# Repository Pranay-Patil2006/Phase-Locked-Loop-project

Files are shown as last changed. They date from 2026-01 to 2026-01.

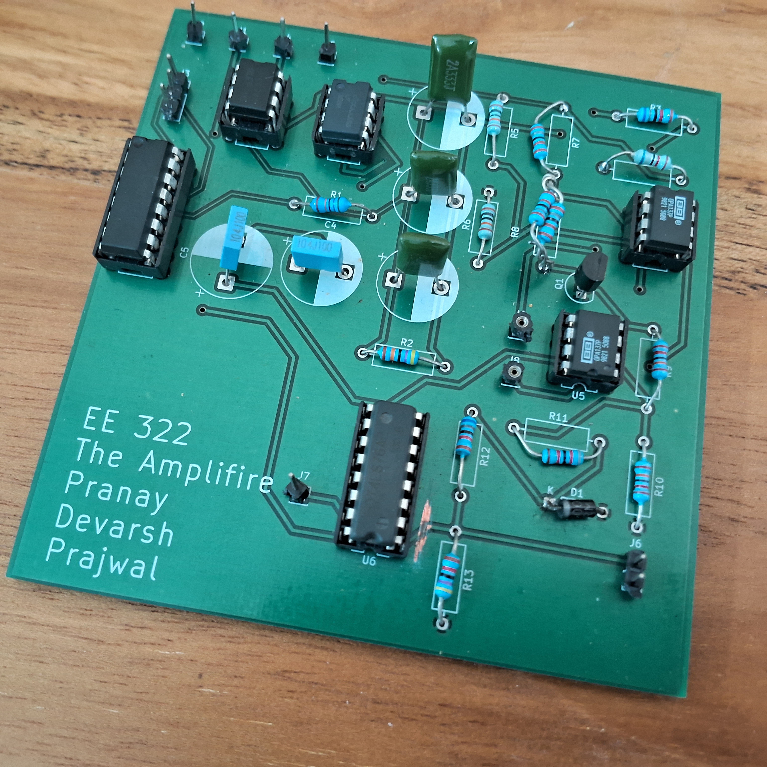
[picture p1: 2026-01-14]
images/PCB_soldered.jpg

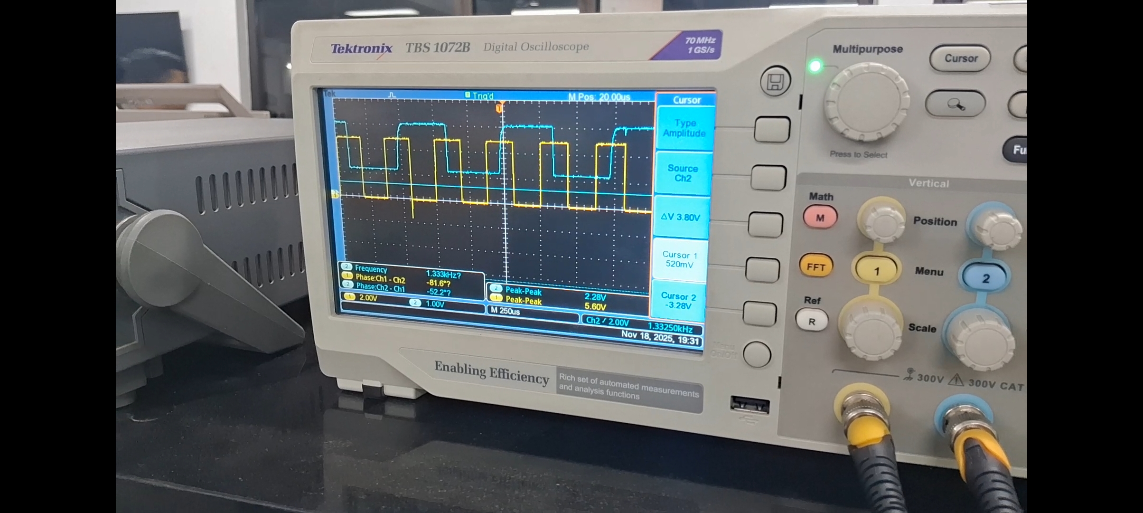
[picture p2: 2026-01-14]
images/Locking.jpg

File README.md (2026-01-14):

# Phase-Locked-Loop Project
**Design and implementation on PCB of a phase-locked loop**

---

## Summary
Designed, simulated, and validated a discrete analog Phase-Locked Loop (PLL) implemented on PCB using a CD4046 phase detector, discrete op-amps, and passive/active loop-filter components. The design was optimized to minimize phase jitter and maximize capture and lock range, with close agreement between simulation and hardware measurements.

---

## Key Contributions
- **Loop design & analysis:** Derived loop-filter values from the closed-loop transfer function; verified lock time and stability margins using time-domain analysis.
- **Simulation strategy:** Performed LTSpice transient simulations and parameter sweeps to evaluate capture range, locking behavior, and sensitivity to component variations.
- **Jitter reduction tactics:** Reduced jitter through optimized loop bandwidth selection, low-noise op-amp choice, VCO linearization, proper supply decoupling, and careful PCB routing of phase detector and VCO control nodes.
- **Validation:** Conducted testbench measurements of lock acquisition and short-term phase stability to confirm simulation trends and guide final component tuning.

---

## Block Diagram
Simple block diagram of the circuit

*Credits: https://electronicscoach.com/phase-locked-loops.html*

---

## Results
- **Measured capture/lock range:** 150Hz - 1300Hz

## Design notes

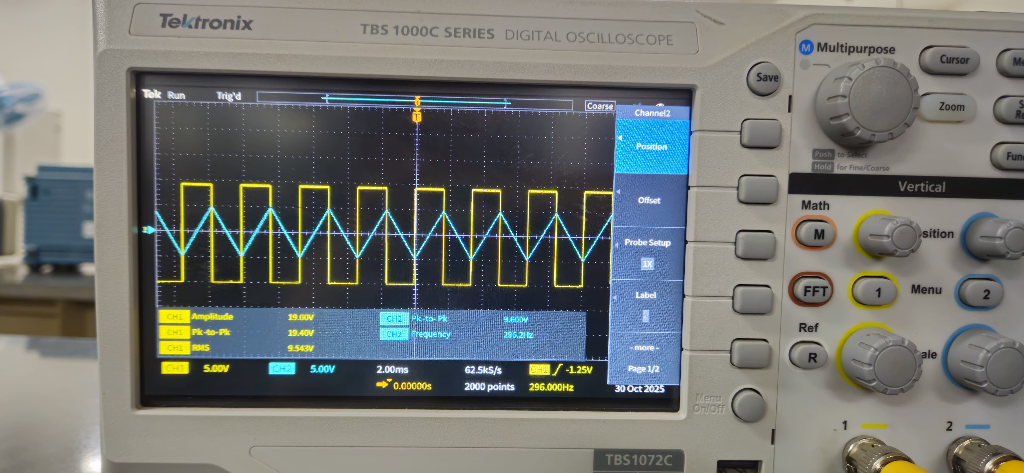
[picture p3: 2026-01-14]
images/VCO_output.jpg

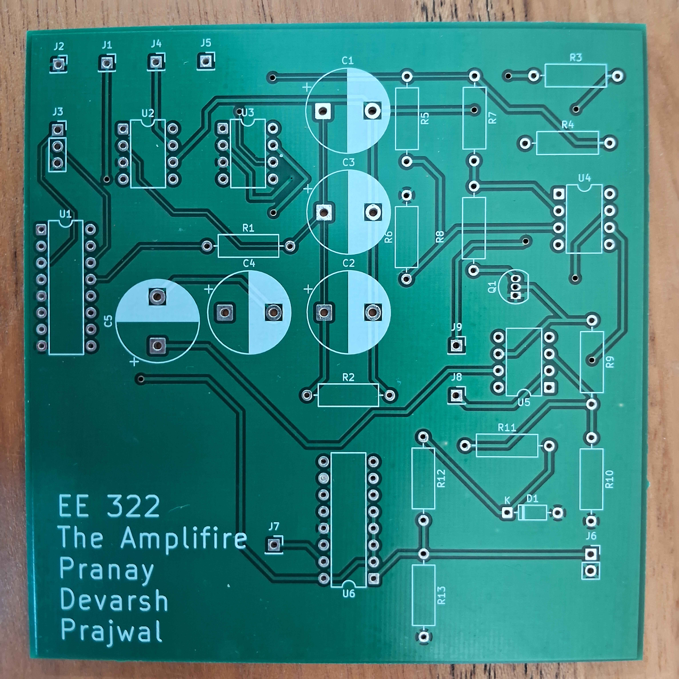
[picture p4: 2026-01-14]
images/PCB.jpg

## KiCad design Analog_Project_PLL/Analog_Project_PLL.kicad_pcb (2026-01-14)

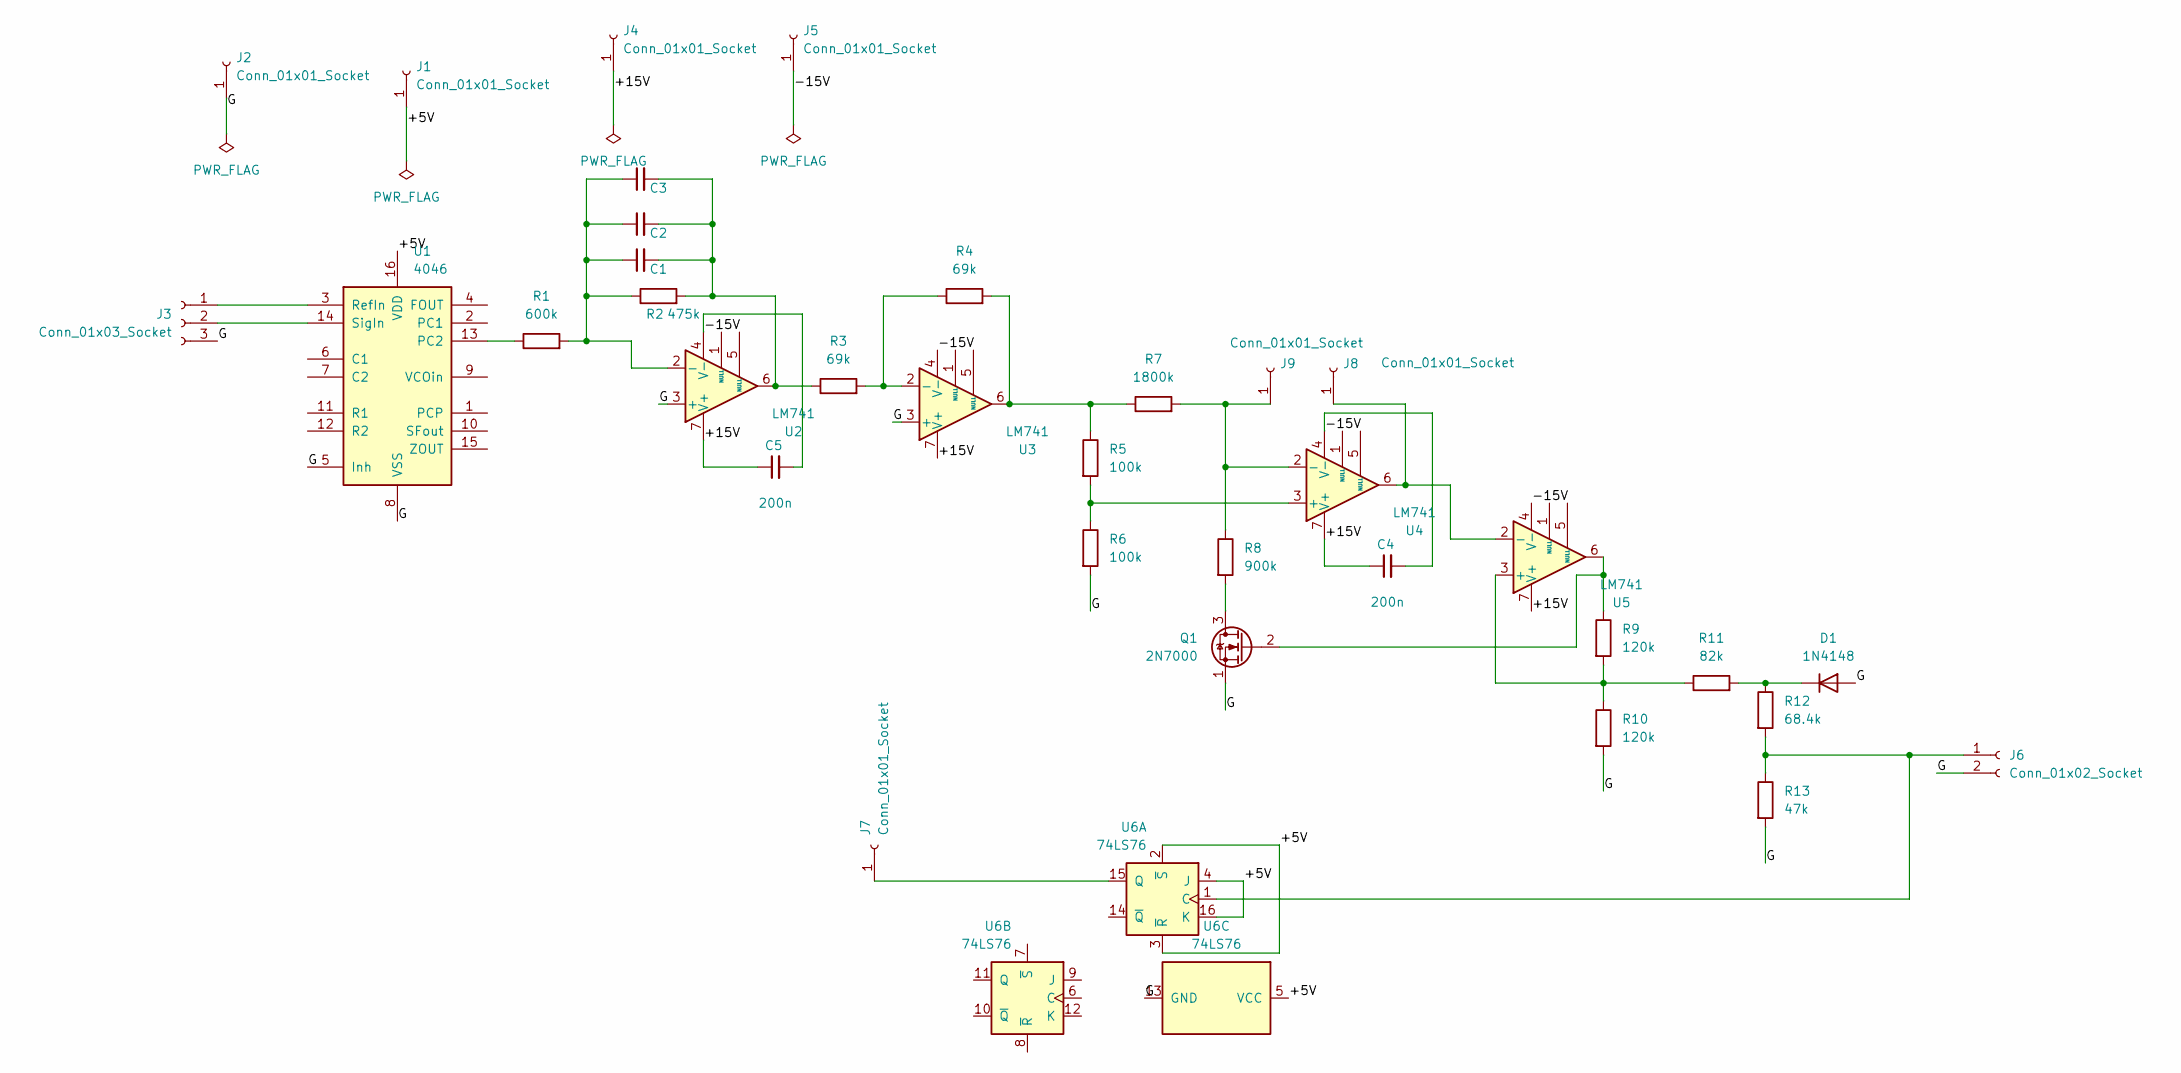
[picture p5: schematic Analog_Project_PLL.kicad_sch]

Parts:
C1, C2, C3: 33n; CP_Radial_D12.5mm_P7.50mm
C4, C5: 200n; CP_Radial_D12.5mm_P7.50mm
D1: 1N4148; D_DO-35_SOD27_P7.62mm_Horizontal
J1, J2, J4, J5, J7, J8, J9: Conn_01x01_Socket; PinSocket_1x01_P2.54mm_Vertical
J3: Conn_01x03_Socket; PinSocket_1x03_P2.54mm_Vertical
J6: Conn_01x02_Socket; PinSocket_1x02_P2.54mm_Vertical
Q1: 2N7000; TO-92_Inline
R1: 600k; R_Axial_DIN0309_L9.0mm_D3.2mm_P12.70mm_Horizontal
R2: 475k; R_Axial_DIN0309_L9.0mm_D3.2mm_P12.70mm_Horizontal
R3, R4: 69k; R_Axial_DIN0309_L9.0mm_D3.2mm_P12.70mm_Horizontal
R5, R6: 100k; R_Axial_DIN0309_L9.0mm_D3.2mm_P12.70mm_Horizontal
R7: 1800k; R_Axial_DIN0309_L9.0mm_D3.2mm_P12.70mm_Horizontal
R8: 900k; R_Axial_DIN0309_L9.0mm_D3.2mm_P12.70mm_Horizontal
R9, R10: 120k; R_Axial_DIN0309_L9.0mm_D3.2mm_P12.70mm_Horizontal
R11: 82k; R_Axial_DIN0309_L9.0mm_D3.2mm_P12.70mm_Horizontal
R12: 68.4k; R_Axial_DIN0309_L9.0mm_D3.2mm_P12.70mm_Horizontal
R13: 47k; R_Axial_DIN0309_L9.0mm_D3.2mm_P12.70mm_Horizontal
U1: 4046; DIP-16_W7.62mm
U2, U3, U4, U5: LM741; DIP-8_W7.62mm
U6: 74LS76; DIP-16_W7.62mm

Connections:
/+5V: J1.1, U1.16 (VDD), U6.2 (~S), U6.3 (~R), U6.4 (J), U6.5 (VCC), U6.16 (K)
/+15V: C4.1, C5.1, J4.1, U2.7 (V+), U3.7 (V+), U4.7 (V+), U5.7 (V+)
/-15V: C4.2, C5.2, J5.1, U2.4 (V-), U3.4 (V-), U4.4 (V-), U5.4 (V-)
/G: D1.2 (A), J2.1, J3.3, J6.2, Q1.1 (S), R6.2, R10.2, R13.2, U1.5 (Inh), U1.8 (VSS), U2.3 (+), U3.3 (+), U6.13 (GND)
unnamed: C1.2, C2.2, C3.2, R2.2, R3.1, U2.6
unnamed: D1.1 (K), R11.2, R12.1
unnamed: J3.1, U1.3 (RefIn)
unnamed: J3.2, U1.14 (SigIn)
unnamed: J6.1, R12.2, R13.1, U6.1 (C)
unnamed: J7.1, U6.15 (Q)
unnamed: J8.1, U4.6, U5.2 (-)
unnamed: J9.1, R7.2, R8.1, U4.2 (-)
unnamed: Q1.3 (D), R8.2
unnamed: Q1.2 (G), R9.1, U5.6
unnamed: R4.2, R5.1, R7.1, U3.6
unnamed: R1.1, U1.13 (PC2)
unnamed: C1.1, C2.1, C3.1, R1.2, R2.1, U2.2 (-)
unnamed: R3.2, R4.1, U3.2 (-)
unnamed: R5.2, R6.1, U4.3 (+)
unnamed: R9.2, R10.1, R11.1, U5.3 (+)

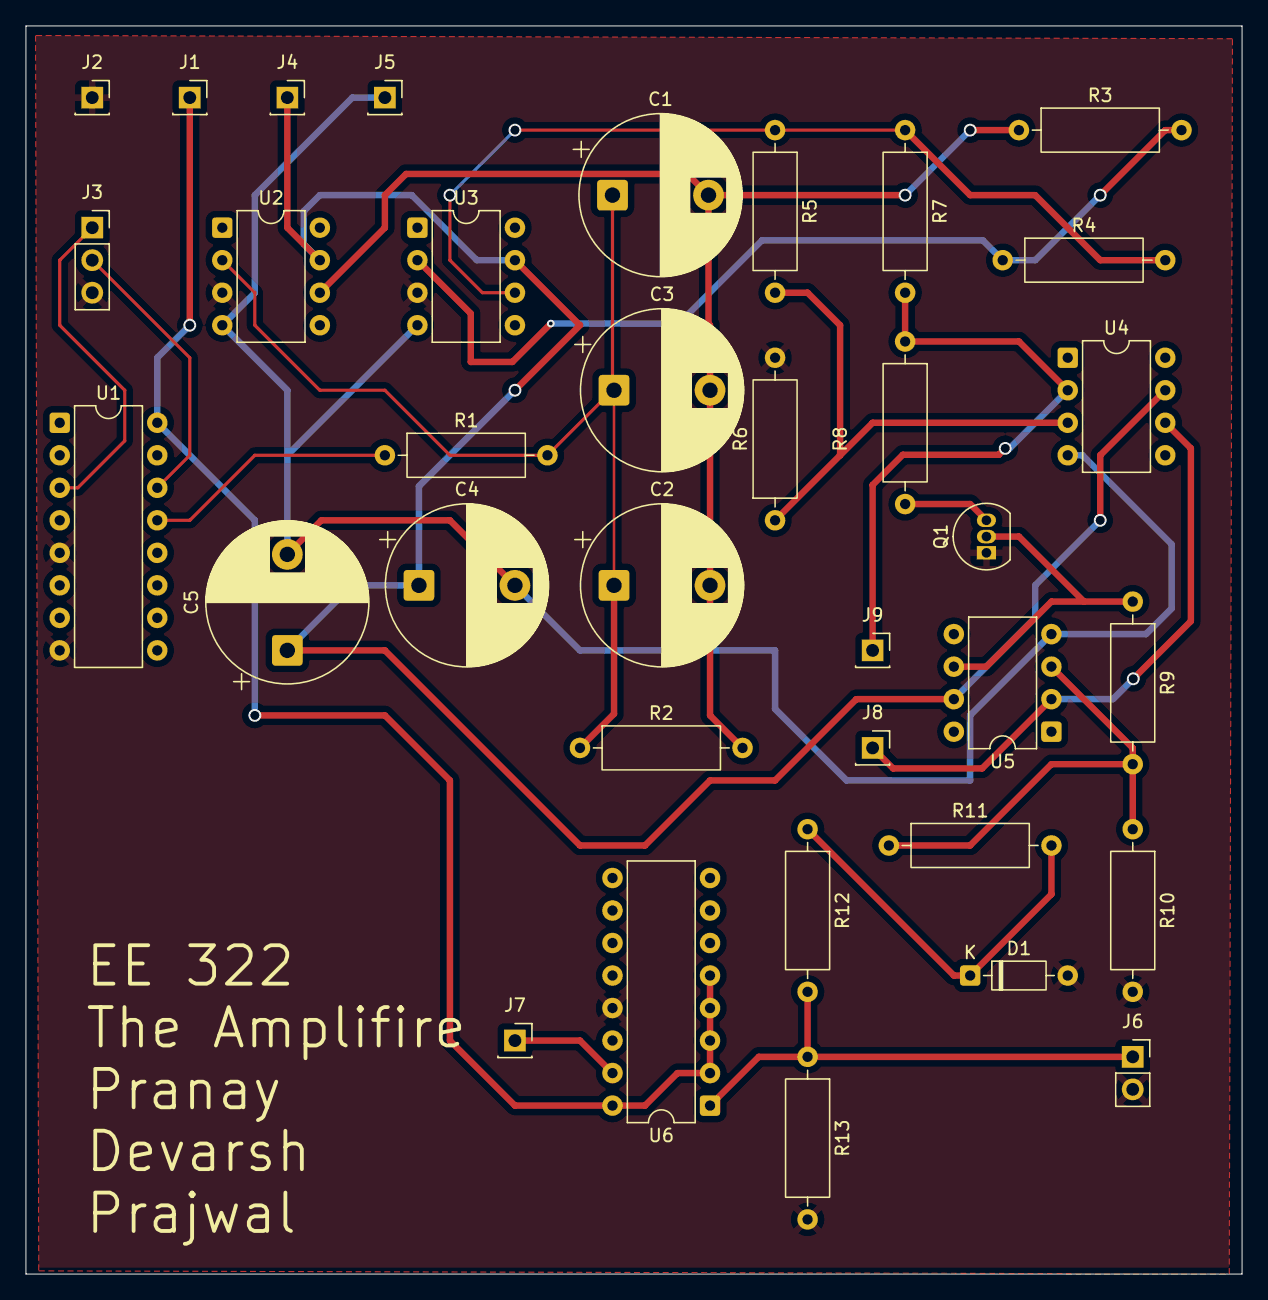
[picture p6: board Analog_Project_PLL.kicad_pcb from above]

Board: 2 copper layers, 95.0 x 97.5 mm, 35 parts (0 on the bottom side), 20 nets.
